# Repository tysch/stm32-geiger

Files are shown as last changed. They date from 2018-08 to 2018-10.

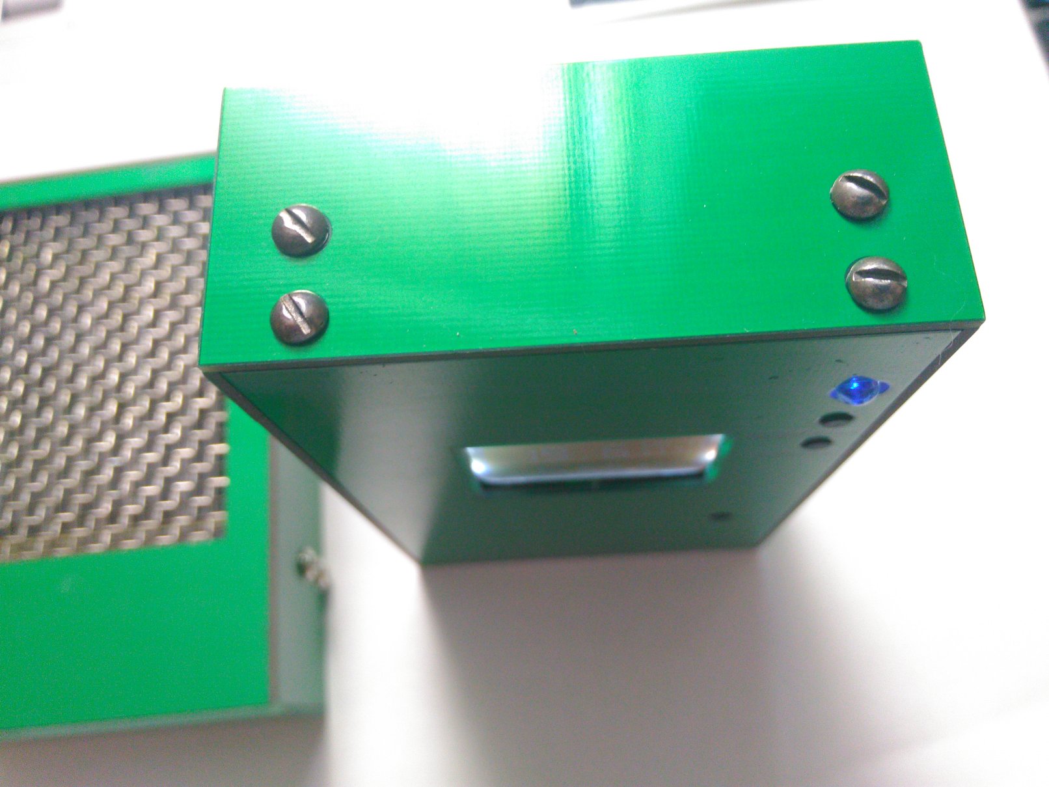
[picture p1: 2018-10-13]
Case and assembly/13.jpg

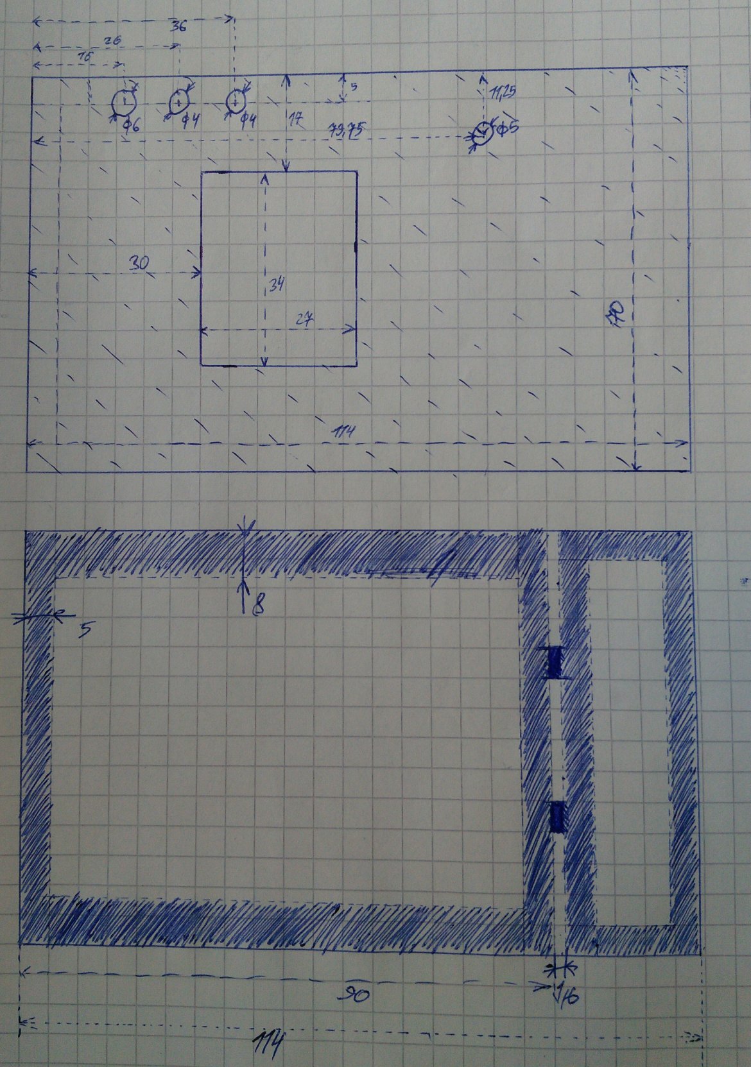
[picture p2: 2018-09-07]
Case and assembly/Case_Drawing/Case_Front_Back.jpg

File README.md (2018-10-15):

# STM32-based Geiger Counter

Simple geiger counter, tailored for DIY assembly and home usage.

## Disclaimer: this is not a legal radiation measurement device. It is neither proofed to be accurate, nor reliable. It is not authorized for any regulatory or safety usage, and any results obtained with this device must be verified with a proper equipment. Do not do any operations with radioactive materials that are not complying to local regulations. I have no responsibility for any harm caused by use of this device.

## CAUTION: HIGH VOLTAGE! This device contains 400V power source. Pay attention to safety and do not use this device without front panel attached.

## Key features of stm32-geiger:

1. Neat FR-4 case that is composed with solder-jointed PCBs. PCBs can be also DIY, or outsourced to numerous manufacturers, eliminating complex tooling for single device assembly.
2. Pancake-style detector СБТ-10А, highly sensitive to alpha, beta and gamma radiation. Case is built with provision of filtering out alpha and beta via steel cover.
3. Differential measurement mode for automatic ambient radiation compensation for measuring any traces of contamination.
4. Separate reading with guaranteed 3-seconds latency for searching for high intensity sources.
5. Electronics is designed to avoid any unique or prone to failures components like custom transformers. All components except gm tube are available off-the-shelf.
6. Single 18650 Li battery and micro-USB charging port. Working time is 3-10 days, depends on capacity, radiation intensity and use of display backlight.
7. Nokia 5110 display is readable both at sunlight and in full darkness. The backlight can be turned off for prolonging battery life.
8. Led blinking and sound ticks on particle detection.

## Key shortcomings:
1. СБТ-10А is very fragile. This geiger counter is not suitable for active outdoor use. There is no way to combine alpha and beta sensitivity with ruggedness,
   and my goal was to build as sensitive device as it is possible with reasonable efforts, though the electronics circuit can be useful for other projects.
2. СБТ-10А and electronic circuit are not designed for high levels of radiation. Theoretical limit for this setup is 50mR/h and there is no indication for overloading.
   Never use this device if higher radiation levels are possible, it is intended for low level measurements.
3. Background radiation compensation feature is designed in mind that background radiation level is not changing. Don't even try to measure for 1 month for 1 nR/h difference.
   Also, pancake-style tubes are sensitive to pressure, ambient illumination and have comparably high noise, for pure gamma measurements scintillator-type counters would be better choice.
4. СБТ-10А is rare and requires tricky preparations to strip the tube from the original bulky case. It is possible to redesign the case to use more common GM tubes, but they are
   less sensitive to beta and cannot detect alpha particles at all. 
5. This device is uncalibrated and currently is not distinguishing gamma dose and alpha and beta particles density. The latter can be added in software if necessary.
   There is also a plenty room for software upgrades, i.e., logging facilities, continuous monitoring mode, interaction with PC etc but I'm lacking time and use cases to implement them for myself.

stm32-geiger is optimized for detecting radioactive artifacts like a contaminated food, uranium glass, self-illuminated paintings etc.

For maximum sensitivity, СБТ-10А tube is being used. It has large detecting surface and is very sensitive to beta-particles. 
To fit the tube into pocket-sized device, it's external case was removed. It can be done by cutting off external pins and careful sawing the case slightly above the glued joint with the tube, or by 
drilling the hole in a side wall and syringing some toluene-based solvent. Wait for a while, and the tube can be detached from the case. Be extremely careful with mechanical preparations of there tubes, the mica window have only a few microns thickness and the tubes are underpressured and can explode on shock or piercing.

The case is inspired by https://hackaday.com/2015/06/03/how-to-build-beautiful-enclosures-from-fr4-aka-pcbs/ . It uses 7 PCBs, soldered together to form a rectangular-shaped case with detachable upper wall. The upper wall is fixed with the screws and may be removed for access to the circuitry or for replacing the battery. For filtering out alpha and beta particles and additional protection, steel 
gamma filter can be attached to the back side of counter. It is fixed by magnet salvaged from old HDD glued under the battery section. The steel plate is positioned with an aluminium plate glued on the back side in such a way that it is tightly filling the sensor hole.

The display is a ubiquitous Nokia 5110 module. LCD is beneficial for it's low power consumption for rarely updating data and excellent readability with bright external illumination and ease of use with software SPI. It displays battery charge state, main infinitely averaged and secondary 5-seconds median filtered readings and their error estimations.

stm32f103 is chosen for it's convenience of programming and handful features like a built-in ADC with precision voltage reference that simplifies hardware implementation. It uses low speed main clock (8MHz) and wakes only for particle detections and updates of battery state and readings once a second for prolonging battery life. It also forms a reference 1.21v voltage via PWM for 400v boost converter. 
MCU is constantly running for use of pushbutton power switch, and high voltage converter, LED, display and buzzer are disconnected while power is down via P-fet switch. 

18650 cell is chosen over AA/AAA alkaline cells because of their higher capacity and better price and this device is not intended for outdoor use with constantly replacing batteries in field. For the same reason there is built-in USB charger. The battery can last for a couple of weeks and ensures that any practical long-term measurements can be conducted without interruptions.
Battery is charged with TP4056 charge controller an protected via DW01A.
The system is powered with 3.3v derived from XC6206 LDO.

The step-up converter is PFM-type, based on 74AC14 oscillator and MOSFET with a fixed duty cycle, and LM393 for shutting oscillator down if the output voltage reaches 400v. The boost converter is designed for 40V voltage spikes, multiplied tenfold via voltage multiplier. This design is power efficient for small loading and uses common parts. The inductor is composed from a two parts for lowering voltage spikes stress on it's winding insulation.
The output voltage is monitored from the output of multiplier for better regulation, but it is possible to wire it to C14 to reduce power dissipation on feedback resistor.

LM393 require some voltage reference for this converter. stm32f103 contains decent and low power 1.21v voltage reference, but it is only accessible by ADC. This device measures the relation between the power supply voltage and the reference voltage each second, and use it as a duty cycle setting for PWM. This signal is filtered with low pass filter and forms 1.21V external reference voltage for LM393.

## Usage:

0/Power button: long press to turn the device on/off, short press subtracts currently averaged readings from subsequent ones. The latter feature is useful for long time measurements of small differences in radiation level, just measure the smaller one for a long time, press 0 and measure the difference between old and new level. This is particularly useful for measurement of food contamination.
Short press on 0 resets background subtraction and displays total intensity.
Median filtered value is not affected with background subtraction. 

Light/Ticks button: long press to toggle clicks of particle detection, short press to toggle display illumination

Both main and secondary readings are provided with automatic error estimation. Main error is affected with total particles counted, i.e, the longer is measurement time, the lower is calculated error. However, if background cancellation is used, the total error is affected with uncertainty of background level, and it is impossible to get error margin better than that value. Also one should pay attention to possible small variation of background radiation level, there is no way to automatically distinguish random background variations from the desired changes. Combine the results of repeated background cancelated measurements for getting rid of the background variations and use some additional statistical data conditioning.

Secondary readings are median-filtered and are intended for interactive searching of highly active sources or detecting a short bursts of radiation. The error estimation is based on intensity with an assumption of it's Poisson-like distributed variations and is provided for information purpose only.

## If you want to reproduce this device, watch out for the erratas:

1) XC6206 have mirrored pinout on PCB.
2) DW01A footprint is incorrect, the actual one is SOT23-6 and is bigger.
3) Wire feedback resistors to C14. Use 1M + 1M + 1M resistors to LM393 input, and 91k from lm393 input to ground.
4) LM393 inverting and non-inverting inputs are mirrored.
5) Add reset button. The watchdog operation interferes with the reflashing.
6) Wire blue led directly to MCU because is not, it would draw the power while device is turned off
7) Wire R38 to 74AC14 VCC rail instead of ground for better sharp pulse detection and improved noise immunity. 
8) Recalibrate the counter based on your tube and set a proper NRH_PER_CPS constant in main.c

STM32-geiger was tested with the most common radiation source (potassium fertilizer). Please note that for the gamma level measurement the background radiation level have been cancelled out for a 10 hours, that low level measurements takes and extremely long time to complete.

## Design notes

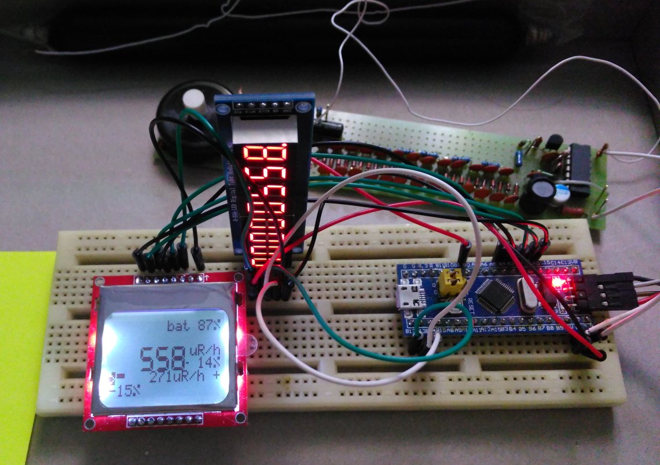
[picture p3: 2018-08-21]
Hardware/Schematic/prototyping.jpg

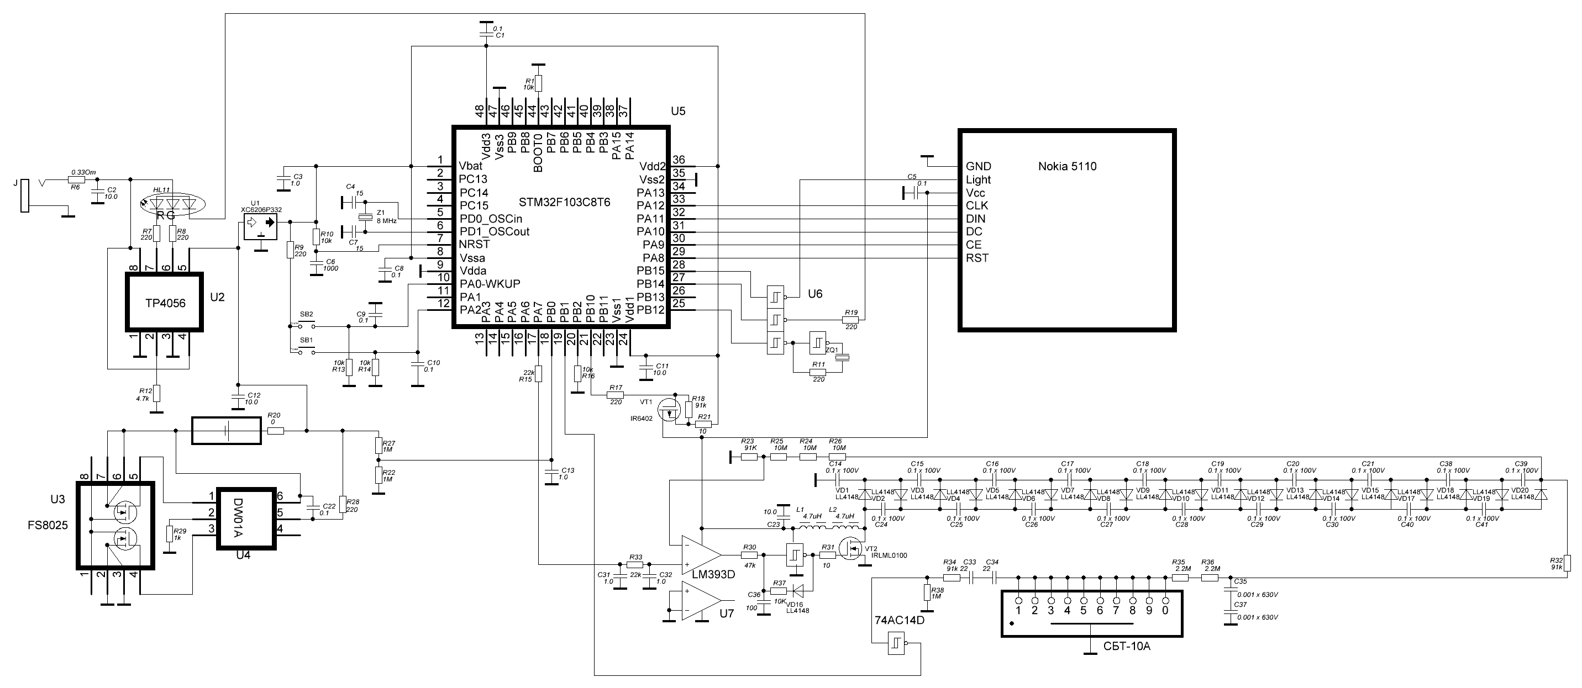
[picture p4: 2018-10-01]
Hardware/Schematic/geiger.GIF

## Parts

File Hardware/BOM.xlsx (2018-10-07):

Designator | Part number | Package | Qty
U1 | XC6206P332 | SOT-23 | 1
U2 | TP4056 | SO-8 | 1
U3 | FS8205 | TSSOP-8 | 1
U4 | DW01A | SOT23-6 | 1
U5 | STM32F103C8T6 | LQFP64 | 1
U6 | SN74AC14D | SO-14 | 1
U7 | LM393D | SO-8 | 1
R1,R10,R13,R14,R16,R37 | 10k | -- 0805 | 6
R7,R8,R9,R11,R17,R19,R28 | 220 | -- 0805 | 7
R6 | 0.33Ohm | -- 0805 | 1
R12 | 4.7k | -- 0805 | 1
R15,R33 | 22k | -- 0805 | 2
R18,R23,R32,R34 | 91k | -- 0805 | 4
R20 | 0 | -- 1206 | 1
R21,R31 | 10 | -- 0805 | 2
R22,R27,R38 | 1M | -- 0805 | 3
R24,R25,R26 | 10M | -- 1206 | 3
R29 | 1k | -- 0805 | 1
R30 | 47k | -- 0805 | 1
R35,R36 | 2.2M | -- 1206 | 2
C1,C5,C8,C9,C10,C14,C15,C16,C17,C18 | 0.1uF 100V | -- 0805 | 25
C19,C20,C21,C22,C24,C25,C26,C27,C28,C29,C30,С38,С39,С40,С41
C2,C11,C12,C23 | 10uF | -- 1206 | 4
C3,C13,C31,C32 | 1uF | -- 0805 | 4
C4,C7 | 15pF | -- 0805 | 2
C6 | 1nF | -- 0805 | 1
C33,C34 | 22pF 1kV | -- 1206 | 2
C35,C37 | 10nF 1kV | -- 1206 | 2
C36 | 100p | -- 0805 | 1
VD1-VD20 | LL4148 | SOD-80 | 20
VT1 | IR6402 | SOT23 | 1
VT2 | IRLML0100 | SOT23 | 1
L1,L2 | 4.7uH | 6x7x4 | 2
Z1 | 8MHz | HC-49U | 1
ZQ1 | piezo | Ф20х3 | 1
SB1,SB2 |  |  | 2
X1 | Micro-USB |  | 1
HL11 | red+green+blue | 5mm | 1
8x2.54mm pin header |  |  | 2
nuts M3x5 brass |  |  | 8
SMD passives sizes are in imperial units

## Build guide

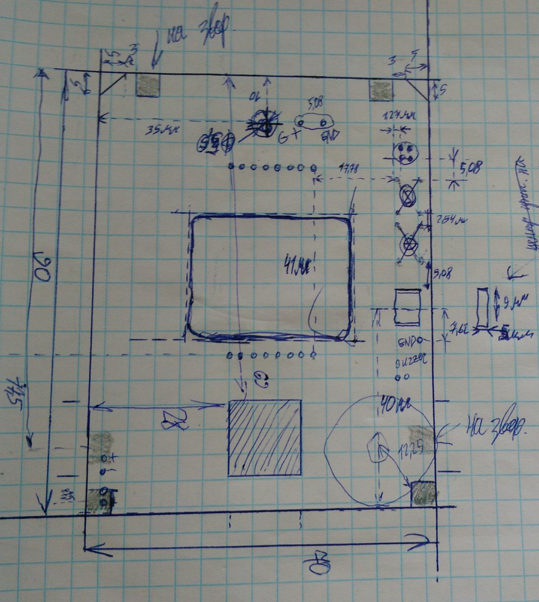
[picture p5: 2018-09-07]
Case and assembly/Case_Drawing/Main_PCB.jpg

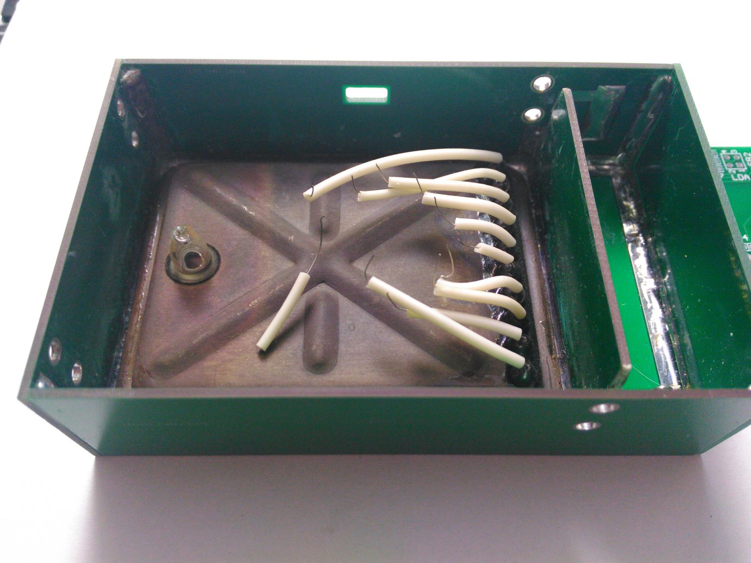
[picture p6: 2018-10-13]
Case and assembly/8.jpg

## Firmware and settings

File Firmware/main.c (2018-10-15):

#include <stdint.h>

#include "stm32_lib/stm32f10x.h"
#include "stm32_lib/stm32f10x_conf.h"
#include "stm32_lib/system_stm32f10x.h"

#include "xprintf.h"
#include "driver_5110_lcd.h"

#include "display.h"
#include "filters.h"
#include "adc.h"
#include "beep.h"
#include "led_blink.h"


/////////////////////////////////////////////////////////////////////////////////////////////
//
//    Settings
//
/////////////////////////////////////////////////////////////////////////////////////////////


#define NRH_PER_CPS 7000                // multiplier, nR/h per one pulse per second

#define BUTTON_LONG_PRESS_DELAY 2       // in seconds

#define MAX_VOLTAGE 4200                // Voltage range for battery
#define MIN_VOLTAGE 2700

/////////////////////////////////////////////////////////////////////////////////////////////
//
//    Global data
//
/////////////////////////////////////////////////////////////////////////////////////////////

static volatile uint32_t seconds = 0;

static volatile uint32_t counts = 0;
static volatile uint32_t prev_counts = 0;

static volatile uint32_t nrh = 0;
static volatile uint8_t  error = 0;

static volatile uint32_t background_nrh = 0;
static volatile uint8_t background_err = 0;

static volatile uint8_t backlight = 0;
static volatile uint8_t is_beeping;
static volatile uint8_t batt_charge;

static uint8_t vcc_voltage_monitor_started = 0;

uint32_t invsqrt(uint32_t n);

/////////////////////////////////////////////////////////////////////////////////////////////
//
//    Initizlizations
//
/////////////////////////////////////////////////////////////////////////////////////////////


void watchdog_timer_init (void) // Fires each 3,5 seconds
{
  /* Enable the LSI OSC */
	RCC_LSICmd(ENABLE);   //Enable LSI Oscillator
	while (RCC_GetFlagStatus(RCC_FLAG_LSIRDY) == RESET) {}// Wait till LSI is ready
	IWDG_WriteAccessCmd(IWDG_WriteAccess_Enable);         // Enable Watchdog
	IWDG_SetPrescaler(IWDG_Prescaler_32);                 // 4, 8, 16 ... 256
	IWDG_SetReload(0x0FFF);                     //This parameter must be a number between 0 and 0x0FFF.
	IWDG_ReloadCounter();                       //Initial watchdog reset
	IWDG_Enable();
}

void SetHSE(void)
{
    ErrorStatus HSEStartUpStatus;
    // SYSCLK, HCLK, PCLK2 and PCLK1 configuration 
    RCC_DeInit();
    // Enable HSE 
    RCC_HSEConfig(RCC_HSE_ON);
    // Wait till HSE is ready 
    HSEStartUpStatus = RCC_WaitForHSEStartUp();
    if (HSEStartUpStatus == SUCCESS)
    {
        // HCLK = SYSCLK
        RCC_HCLKConfig( RCC_SYSCLK_Div1);
        // PCLK2 = HCLK
        RCC_PCLK2Config( RCC_HCLK_Div1);
        // PCLK1 = HCLK/2
        RCC_PCLK1Config( RCC_HCLK_Div2);
        // Select HSE as system clock source 
        RCC_SYSCLKConfig(RCC_SYSCLKSource_HSE);
    }
    else
    { // If HSE fails to start-up, the application will have wrong clock configuration.
        while (1)
        {
        }
    }
}

// Fires once per second and updates readings
void init_display_timer(void) 
{
    // Enable TIM4
    TIM_TimeBaseInitTypeDef TIMER_InitStructure;
    NVIC_InitTypeDef NVIC_InitStructure;
    RCC_APB1PeriphClockCmd(RCC_APB1Periph_TIM4, ENABLE);
    TIM_TimeBaseStructInit(&TIMER_InitStructure);
    TIMER_InitStructure.TIM_CounterMode = TIM_CounterMode_Up;
    // TIMER_InitStructure.TIM_Prescaler = 7200;
    TIMER_InitStructure.TIM_Prescaler = 800;
    TIMER_InitStructure.TIM_Period = 10000;
    TIM_TimeBaseInit(TIM4, &TIMER_InitStructure);
    TIM_ITConfig(TIM4, TIM_IT_Update, ENABLE);
    TIM_Cmd(TIM4, ENABLE);
 
    // Enable the TIM4_IRQn Interrupt 
    NVIC_InitStructure.NVIC_IRQChannel = TIM4_IRQn;
    NVIC_InitStructure.NVIC_IRQChannelPreemptionPriority = 1;
    NVIC_InitStructure.NVIC_IRQChannelSubPriority = 2;
    NVIC_InitStructure.NVIC_IRQChannelCmd = ENABLE;
    NVIC_Init(&NVIC_InitStructure);
}

void pushbuttons_gpio_init(void)
{
    GPIO_InitTypeDef GPIO_InitStruct;
    RCC_APB2PeriphClockCmd(RCC_APB2Periph_GPIOA, ENABLE);
    // Set pins as input 
    GPIO_InitStruct.GPIO_Pin = GPIO_Pin_0 | GPIO_Pin_2;
    GPIO_InitStruct.GPIO_Mode = GPIO_Mode_IPD; // Pulldown
    GPIO_InitStruct.GPIO_Speed = GPIO_Speed_2MHz;
    GPIO_Init(GPIOA, &GPIO_InitStruct);
}

// Sets interrupts for pushbuttons on A0 and A2
void pushbuttons_init(void)
{
    //EXTI

    // Set variables used
    
    EXTI_InitTypeDef EXTI_InitStruct;
    NVIC_InitTypeDef NVIC_InitStruct;

    // Enable clock for AFIO 
    // Pushbuttons GPIO was iniialized upon watchdog reset
    RCC_APB2PeriphClockCmd(RCC_APB2Periph_AFIO, ENABLE);

    // Add IRQ vector to NVIC
    // PB0 is connected to EXTI_Line0, which has EXTI0_IRQn vector 
    NVIC_InitStruct.NVIC_IRQChannel = EXTI0_IRQn;
    // Set priority
    NVIC_InitStruct.NVIC_IRQChannelPreemptionPriority = 1;
    // Set sub priority
    NVIC_InitStruct.NVIC_IRQChannelSubPriority = 1;
    // Enable interrupt
    NVIC_InitStruct.NVIC_IRQChannelCmd = ENABLE;
    // Add to NVIC
    NVIC_Init(&NVIC_InitStruct);

    // Tell system that you will use PA0 for EXTI_Line0
    GPIO_EXTILineConfig(GPIO_PortSourceGPIOA, GPIO_PinSource0);

    // PD0 is connected to EXTI_Line0
    EXTI_InitStruct.EXTI_Line = EXTI_Line0;
    // Enable interrupt
    EXTI_InitStruct.EXTI_LineCmd = ENABLE;
    // Interrupt mode 
    EXTI_InitStruct.EXTI_Mode = EXTI_Mode_Interrupt;
    // Triggers on rising and falling edge
    EXTI_InitStruct.EXTI_Trigger = EXTI_Trigger_Rising_Falling;
    // Add to EXTI
    EXTI_Init(&EXTI_InitStruct);

    // Add IRQ vector to NVIC
    // PB0 is connected to EXTI_Line2, which has EXTI2_IRQn vector
    NVIC_InitStruct.NVIC_IRQChannel = EXTI2_IRQn;
    // Set priority
    NVIC_InitStruct.NVIC_IRQChannelPreemptionPriority = 1;
    // Set sub priority
    NVIC_InitStruct.NVIC_IRQChannelSubPriority = 1;
    // Enable interrupt
    NVIC_InitStruct.NVIC_IRQChannelCmd = ENABLE;
    // Add to NVIC
    NVIC_Init(&NVIC_InitStruct);
 
    // Tell system that you will use PA2 for EXTI_Line2
    GPIO_EXTILineConfig(GPIO_PortSourceGPIOA, GPIO_PinSource2);
 
    // PD0 is connected to EXTI_Line2
    EXTI_InitStruct.EXTI_Line = EXTI_Line2;
    // Enable interrupt
    EXTI_InitStruct.EXTI_LineCmd = ENABLE;
    // Interrupt mode
    EXTI_InitStruct.EXTI_Mode = EXTI_Mode_Interrupt;
    // Triggers on rising and falling edge
    EXTI_InitStruct.EXTI_Trigger = EXTI_Trigger_Rising_Falling;
    // Add to EXTI
    EXTI_Init(&EXTI_InitStruct);
}



// Interrupts upon pulse from geiger counter on pin PB1
void geiger_counter_input_init()
{
    // Set variables used
    GPIO_InitTypeDef GPIO_InitStruct;
    EXTI_InitTypeDef EXTI_InitStruct;
    NVIC_InitTypeDef NVIC_InitStruct;

    // Enable clock for AFIO
    RCC_APB2PeriphClockCmd(RCC_APB2Periph_AFIO, ENABLE);

    // Set pin as input
    GPIO_InitStruct.GPIO_Pin = GPIO_Pin_1;
    GPIO_InitStruct.GPIO_Mode = GPIO_Mode_IPD;
    GPIO_InitStruct.GPIO_Speed = GPIO_Speed_10MHz;
    GPIO_Init(GPIOB, &GPIO_InitStruct);
 
    // Add IRQ vector to NVIC
    // PB1 is connected to EXTI_Line1, which has EXTI1_IRQn vector
    NVIC_InitStruct.NVIC_IRQChannel = EXTI1_IRQn;
    // Set maximum possible priority 
    NVIC_InitStruct.NVIC_IRQChannelPreemptionPriority = 0;
    // Set sub priority
    NVIC_InitStruct.NVIC_IRQChannelSubPriority = 0;
    // Enable interrupt
    NVIC_InitStruct.NVIC_IRQChannelCmd = ENABLE;
    // Add to NVIC
    NVIC_Init(&NVIC_InitStruct);

    // Tell system that you will use PB1 for EXTI_Line1
    GPIO_EXTILineConfig(GPIO_PortSourceGPIOB, GPIO_PinSource1);

    // PD0 is connected to EXTI_Line1
    EXTI_InitStruct.EXTI_Line = EXTI_Line1;
    // Enable interrupt
    EXTI_InitStruct.EXTI_LineCmd = ENABLE;
    // Interrupt mode
    EXTI_InitStruct.EXTI_Mode = EXTI_Mode_Interrupt;
    // Triggers on rising and falling edge
    EXTI_InitStruct.EXTI_Trigger = EXTI_Trigger_Rising_Falling;
    // Add to EXTI
    EXTI_Init(&EXTI_InitStruct);
}

/////////////////////////////////////////////////////////////////////////////////////////////
//
//    Pushbuttons actions
//
/////////////////////////////////////////////////////////////////////////////////////////////

// Toggles background correction and resets errors estimation
void subtract_background(void)
{
    if(background_nrh) background_nrh = 0;
    else               background_nrh = NRH_PER_CPS * counts / seconds;

    background_err = invsqrt(counts);
    seconds = 0;
    counts = 0;
    prev_counts = 0;
}

// Short button 1 press, subtracts background
void EXTI0_IRQHandler(void) 
{
    if (EXTI_GetITStatus(EXTI_Line0) != RESET) 
    {
        if (GPIO_ReadInputDataBit(GPIOA, GPIO_Pin_0) != 0) 
        {
            subtract_background();
        }
        // Clear interrupt flag
        EXTI_ClearITPendingBit(EXTI_Line0);
    }
}

// Short button2 press, toggle LCD backlight
void EXTI2_IRQHandler(void) 
{
    if (EXTI_GetITStatus(EXTI_Line2) != RESET)
    {
        if(GPIO_ReadInputDataBit(GPIOA, GPIO_Pin_2) != 0) 
        {
            backlight ^= 0xff;
            LCD5110_Led(backlight); 
        }
        // Clear interrupt flag
        EXTI_ClearITPendingBit(EXTI_Line2);
    }
}

//
//         Actions upon long pressing
//

void shutdown(void)
{
    PWR_EnterSTANDBYMode();
}

void reset_counts(void)
{
    seconds = 0;
    counts = 0;
    prev_counts = 0;
    background_nrh = 0;
}

void button_1_shutdown(int is_pressed)
{
    static uint8_t cnt = 0;

    if(is_pressed) cnt++;
    else           cnt = 0;

    if(cnt > BUTTON_LONG_PRESS_DELAY) shutdown();
}

void button_2_toggle_beeping(int is_pressed)
{
    static uint8_t cnt = 0;

    if(is_pressed) cnt++;
    else           cnt = 0;

    if(cnt > BUTTON_LONG_PRESS_DELAY) is_beeping ^= 0xff;
}



/////////////////////////////////////////////////////////////////////////////////////////////
//
//    Main program flow
//
/////////////////////////////////////////////////////////////////////////////////////////////



// Called upon each particle detection
void EXTI1_IRQHandler(void)
{
    // Make sure that interrupt flag is set
    if(EXTI_GetITStatus(EXTI_Line1) != RESET) 
    {
        if(GPIO_ReadInputDataBit(GPIOB, GPIO_Pin_1) != 0)
        {
            ++counts; // Total particles detected

            if(is_beeping) beep();
            led_blink();
        }
        // Clear interrupt flag
        EXTI_ClearITPendingBit(EXTI_Line1);
    }
}

// 300/sqrt(n), 3-sigma error estimation with range conditioning
uint32_t invsqrt(uint32_t n)
{
    uint32_t ret = 2;
    if(n < 10) return 99; 
    if(n > 89999) return 1;
    for(uint8_t i = 0; i < 16; i++) // Newton's iteration for 1/ret^2 - n/90000 == 0
    {
        ret = (1 + 3*ret - (n*ret*ret*ret)/90000);
        ret >>= 1;
    }
    return ret;
}

void compute_and_display_values(void)
{
    uint32_t tmp;
    uint32_t err;

    uint32_t fast_nrh;
    uint32_t fast_error;

    // Check for integer overflows
    if(counts > (2*1000*1000*1000/NRH_PER_CPS)) reset_counts();

    tmp = NRH_PER_CPS * counts / seconds; // compute averaged intensity

    if(tmp < background_nrh) nrh = 0;
    else nrh = tmp - background_nrh;      // subtract background if it is set

    if(background_err == 0) err = invsqrt(counts); // compute error
    else
    {
        if(nrh == 0) err = 99;
        else err = (background_err * background_nrh + invsqrt(counts)*tmp) / (nrh); 
        if(err > 99) err = 99;
    }

    fast_nrh = median_filter(NRH_PER_CPS*(counts-prev_counts)); // median filtered 5 last readings
    fast_error = invsqrt(fast_nrh / NRH_PER_CPS);

    LCD5110_clear();
    update_display(is_beeping, batt_charge, nrh, err, fast_nrh, fast_error);
}

// Updates display reading once per second and measures battery charge
void TIM4_IRQHandler(void)
{
    uint32_t voltage;
    if (TIM_GetITStatus(TIM4, TIM_IT_Update) != RESET)
    {
        ++seconds;

        voltage = vcc_voltage();

        if((voltage < MIN_VOLTAGE) && vcc_voltage_monitor_started)
            shutdown();
        else 
            batt_charge = (voltage - MIN_VOLTAGE) / ((MAX_VOLTAGE - MIN_VOLTAGE) / 100);

        button_1_shutdown(GPIO_ReadInputDataBit(GPIOA, GPIO_Pin_0));
        button_2_toggle_beeping(GPIO_ReadInputDataBit(GPIOA, GPIO_Pin_2));

        compute_and_display_values();

        prev_counts = counts;

        IWDG_ReloadCounter();

        TIM_ClearITPendingBit(TIM4, TIM_IT_Update);
    }
}

void enable_display_power(void)
{
    RCC_APB2PeriphClockCmd(RCC_APB2Periph_GPIOB, ENABLE);
    GPIO_InitTypeDef GPIOB_Init;
    GPIOB_Init.GPIO_Pin = GPIO_Pin_10;
    GPIOB_Init.GPIO_Speed = GPIO_Speed_2MHz;
    GPIOB_Init.GPIO_Mode = GPIO_Mode_Out_PP;
    GPIO_Init(GPIOB,&GPIOB_Init);

    GPIO_ResetBits(GPIOB, GPIO_Pin_10);
}


int main(void)
{
    pushbuttons_gpio_init();
    watchdog_timer_init();
    IWDG_ReloadCounter();

    if(GPIO_ReadInputDataBit(GPIOA, GPIO_Pin_0) == 0) // Waked up upon IWDT reset
        shutdown();

    SetHSE();
    NVIC_PriorityGroupConfig(NVIC_PriorityGroup_1);

    enable_display_power();

    LCD5110_init();
    LCD5110_Led(0); 
    LCD5110_set_XY(0,0);
    LCD5110_write_string("Initializing..");

    pushbuttons_init();
    vcc_voltage_monitor_init();
    beep_init();
    led_init();

    init_display_timer();
    geiger_counter_input_init();

    // ENABLE Wake Up Pin
    RCC_APB1PeriphClockCmd(RCC_APB1Periph_PWR,ENABLE);
    PWR_WakeUpPinCmd(ENABLE);

    vcc_voltage_monitor_started = 1;
 
    while(1)
    {
        __WFE();
    }
}

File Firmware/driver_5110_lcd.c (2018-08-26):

#include "driver_5110_lcd.h"
#include "font.h"
#include "stm32f10x.h"
#include <stdio.h>
#include <string.h>

static void Delay_ms(unsigned long nCount)
{
    volatile unsigned long t;
	t = nCount * 72000;
	while(t--);
}

//Define the LCD Operation function
void LCD5110_LCD_write_byte(unsigned char dat, unsigned char LCD5110_MOde);

//Define the hardware operation function
static void LCD5110_GPIO_Config(void);
static void LCD5110_SCK(unsigned char temp);
static void LCD5110_DIN(unsigned char temp);
static void LCD5110_CS(unsigned char temp);
static void LCD5110_RST(unsigned char temp);
static void LCD5110_DC(unsigned char temp);


void LCD5110_SetFont(bool isBig) 
{
   if(isBig == true)
   {
      // You can obtain a pointer to the array block in a Byte array by taking 
      // the address of the first element and assigning it to a pointer.
      _font.font_ptr = &MediumNumbers[0];
   } 
   
   else if(isBig == false)
   {
      // You can obtain a pointer to the array block in a Byte array by taking 
      // the address of the first element and assigning it to a pointer.
      _font.font_ptr = &BigNumbers[0];
   }
   
    _font.x_size = FONT_READ_BYTE(0);     // 12;
    _font.y_size = FONT_READ_BYTE(1);     // 16;
    _font.offset = FONT_READ_BYTE(2);     // 45;
    _font.numchars = FONT_READ_BYTE(3);   // 13;
    _font.inverted = 0;
   
}

/**
 * Set pin configuration. Doesn't use SPI controller. Just regular pins.
 *
 *	PF11 : Reset
 *	PF7  : DC
 *	PF5  : MISO
 *	PF3  : CLK
 *	PF9  : CE
 *	PF1  : LED control
 *
 * @param None
 * @retval None
 */
void LCD5110_GPIO_Config(void) {
  
    GPIO_InitTypeDef GPIO_InitStructure;

//	RCC_HSICmd(DISABLE);
//	RCC_PLLConfig(RCC_PLLSource_HSE_Div1,RCC_PLLMul_9);
//	RCC_PLLCmd(ENABLE);
//	RCC_SYSCLKConfig(RCC_SYSCLKSource_PLLCLK);

//RCC_APB2PeriphClockCmd(RCC_APB2Periph_GPIOA|RCC_APB2Periph_GPIOC, ENABLE);

	RCC_APB2PeriphClockCmd(RCC_APB2Periph_GPIOA | RCC_APB2Periph_GPIOB, ENABLE);

    // Declare pins to configure
    GPIO_InitStructure.GPIO_Pin = LCD_RESET | LCD_DC |  LCD_DATA_IN | LCD_CLK | LCD_CS;// | LCD_BACK_LIGHT; 
    GPIO_InitStructure.GPIO_Speed = GPIO_Speed_10MHz;
    GPIO_InitStructure.GPIO_Mode = GPIO_Mode_Out_PP;
    
    // Init Port
    GPIO_Init(GPIOA, &GPIO_InitStructure);



	GPIO_InitStructure.GPIO_Pin = LCD_BACK_LIGHT; 
    GPIO_InitStructure.GPIO_Speed = GPIO_Speed_10MHz;
    GPIO_InitStructure.GPIO_Mode = GPIO_Mode_Out_PP;
	GPIO_Init(GPIOB, &GPIO_InitStructure);
    
    // Setup default font and size.
    LCD5110_SetFont(true);
    
}


/**
 * Initialize LCD module
 *
 * Input parameters : none
 * Return value		: none
 */
void LCD5110_init(void) {

	//Configure pins
	LCD5110_GPIO_Config();

	// Set pin initial state
	LCD5110_Led(0); //Turn back light off
	LCD5110_RST(0); //Set LCD reset = 0;
	LCD5110_DC(1); //Mode = command;
	LCD5110_DIN(1); //Set In at high level;
	LCD5110_SCK(1); //Set CLK high;
	LCD5110_CS(1); //Unselect chip;

	//Keep reset pin low for 10 ms
	Delay_ms(10);
	//Release Reset Pin
	LCD5110_RST(1); //LCD_RST = 1;

	//Configure LCD module
	LCD5110_LCD_write_byte(0x21, LCD_COMMAND); //Extended instruction set selected
	LCD5110_LCD_write_byte(0xBF, LCD_COMMAND); //Set LCD voltage (defined by experimentation...)
	LCD5110_LCD_write_byte(0x14, LCD_COMMAND); //Set Bias for 1/48
	LCD5110_LCD_write_byte(0x06, LCD_COMMAND); //Set temperature control (TC2)
	LCD5110_LCD_write_byte(0x20, LCD_COMMAND); //Revert to standard instruction set

	LCD5110_clear(); //Clear display (still off)
	LCD5110_LCD_write_byte(0x0c, LCD_COMMAND); //Set display on in "normal" mode (not inversed)
}


/**
 * Write byte to the module.
 *
 * @param dat  	data to write
 * @param mode  0 if command, 1 if data
 *
 * @retval		None
 */
void LCD5110_LCD_write_byte(unsigned char dat, unsigned char mode) {
	unsigned char i;
	LCD5110_CS(0); //SPI_CS = 0;

	if (0 == mode)
		LCD5110_DC(0); //LCD_DC = 0;
	else
		LCD5110_DC(1); //LCD_DC = 1;

	for (i = 0; i < 8; i++) {
		LCD5110_DIN(dat & 0x80); //SPI_MO = dat & 0x80;
		dat = dat << 1;
		LCD5110_SCK(0); //SPI_SCK = 0;
		LCD5110_SCK(1); //SPI_SCK = 1;
	}

	LCD5110_CS(1); //SPI_CS = 1;

}


/**
 * Write character to LCD at current position
 *
 * @param c: char to write
 * @retval None
 */
void LCD5110_write_char(unsigned char c) {
	unsigned char line;
	unsigned char ch = 0;

	c = c - 32;

	for (line = 0; line < 6; line++) {
		ch = font6_8[c][line];
		LCD5110_LCD_write_byte(ch, LCD_DATA);

	}
}

/**
 * Write character to LCD in inverse video at current location
 *
 * @param c: char to write
 * @retval None
 */
void LCD5110_write_char_inv(unsigned char c) {
	unsigned char line;
	unsigned char ch = 0;

	c = c - 32;

	for (line = 0; line < 6; line++) {
		ch = ~font6_8[c][line];
		LCD5110_LCD_write_byte(ch, LCD_DATA);

	}
}

/**
 * Write string to LCD at current position. String must be null terminated.
 *
 * @param s: string pointer
 * @retval None
 */
void LCD5110_write_string(char *s) {
	unsigned char ch;
	while (*s != '\0') {
		ch = *s;
		LCD5110_write_char(ch);
		s++;
	}
}



void LCD5110_num_string(char *s, int x, int row) 
{
  unsigned char ch;
  char m = 0;
  while(*s != '\0') {
    ch = *s;
    LCD5110_num_char(ch, x + (m * (_font.x_size)), row);
    s++;
    m++;
  } 
}



/**
 * Write character to LCD at current position
 *
 * @param c: char to write
 * @retval None
 */
void LCD5110_num_char(unsigned char c, int x, int row) 
{
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

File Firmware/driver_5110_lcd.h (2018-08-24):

#ifndef __DRV_LCD5110__
#define __DRV_LCD5110__

#include <stdbool.h>

#define	LCD_COMMAND	0
#define LCD_DATA 1
#define LCD_RESET GPIO_Pin_8
#define LCD_DC GPIO_Pin_10
#define LCD_DATA_IN GPIO_Pin_11
#define LCD_CLK GPIO_Pin_12
#define LCD_CS GPIO_Pin_9
#define LCD_BACK_LIGHT GPIO_Pin_15
#define LCD_SETYADDR  0x40
#define LCD_SETXADDR  0x80
#define LEFT 0
#define RIGHT 9999
#define CENTER 9998
#define FONT_READ_BYTE(x) _font.font_ptr[x];


void LCD5110_init(void);
void LCD5110_write_char(unsigned char c);
void LCD5110_write_char_inv(unsigned char c);
void LCD5110_clear(void);
void LCD5110_set_XY(unsigned char X, unsigned char Y);
void LCD5110_write_string(char *s);
void LCD5110_write_Dec(unsigned int buffer);
void LCD5110_Led(unsigned char c);
void LCD5110_num_char(unsigned char c, int x, int row);
void printNumF(double num, char dec, int x, int y, char divider, int length, char filler);
void LCD5110_num_string(char *s, int x, int row);
void LCD5110_SetFont(bool isBig);
void LCD5110_drawBitmap(int x, int y, unsigned char* bitmap, int sx, int sy/*, bool flash*/);

struct lcd_font
{
    volatile unsigned char* font_ptr;
    char x_size;
    char y_size;
    char offset;
    char numchars;
    char inverted;
};

volatile static struct lcd_font _font;

#endif

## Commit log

2018-08-11 initial skeleton
    Makefile for arm-gcc, nokia 5110 and hc595 led display drivers
2018-08-11 Added fast and slow counters with averaging and filtering
2018-08-23 Added ticks and led flashes upon detection
2018-08-24 added reference voltage PWM output some reworking of display readings
    [adc.c, driver_5110_lcd.c, driver_5110_lcd.h]
2018-08-26 Lowered clock speed to 8 MHz and Icc to 3mA
2018-09-01 added prototype case
2018-09-07 added case drawings
2018-09-10 added case PCB sources
2018-10-01 added schematic
2018-10-05 added altium schematic and pcb file
    [STM32-geiger.PcbDoc, Schematic_altium.SchDoc]
2018-10-07 added BOM
    [BOM.xlsx]
2018-10-13 added assembling stage photos
2018-10-15 after-assembly code cleaning and fixes
    [adc.c, beep.c, led_blink.c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]
